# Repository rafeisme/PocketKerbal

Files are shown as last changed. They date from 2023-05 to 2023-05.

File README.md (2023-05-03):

# PocketKerbal
Kerbal Space Program Controller using PocketBeagle

(Soon to be) Home to KerbalController!

This is a personalized Kerbal Space Program console built using a PocketBeagle and kRPC. 

More information can be found on my Hackster Page: https://www.hackster.io/rfn1/pocketkerbal-ksp-console-using-pocketbeagle-krpc-d380ad 

The program you need to use/edit is called Project_1_v2
It is actually intiated using a run program. 
For these files, see https://github.com/rafeisme/ENGI301

Currently this repository houses the PCB files for PocketKerbal. These still need some work, but should be functional. The board is the same size as the actual console, and is designed to be fitted behind it. For the sake of simplicity, some of the unique buttons and switches have been temporarily swapped out for generic ones. 
In total there are:
15 toggle switches
4 buttons
20 resistors
2 joysticks
2 potentiometers
2 led bars
2 leds
1 sliding potentiometer
1 display

A more comprehensive parts list can be found on the Hackster Page. 

NOTE: The "PocketBeagle Device" had not been made when the PCB layout was done, so the example PocketBeagle is included here. The file for the custom PocketBeagle is included in the library.
NOTE: The project guidelines mentioned a 4"x5" maximum size, but in order to fit all of the components and be the size of the console, PocketKerbal is 12" x 6". It could be reduced if it was necessary. 
NOTE: The LCD screen was used as opposed to the SPI screen in my library. https://www.adafruit.com/product/181 

This is still a work in progress and will be updated soon.

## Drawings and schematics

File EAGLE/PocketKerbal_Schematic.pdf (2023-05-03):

3.3V P2_23 | SPI1.MOSI P2_25 | SPI1.MISO P2_27 | SPI1.CLK P2_29 | SPI1.CS P2_31 | GPIO45 P2_33 | AIN5(3.3V)GPIO86 P2_35 | GPIO59 | P2_02 GPIO58 | P2_04 GPIO57 | P2_06 GPIO60 | P2_08 GPIO52 | P2_10 PWR.BTN P2_12 | BAT.VIN P2_14 | BAT.TEMP P2_16 | GPIO47 | P2_18 GPIO64 | P2_20 GPIO46 | P2_22 GPIO44 | P2_24 RESET# P2_26 | PRU0.6 | P2_28 PRU0.3 | P2_30 PRU0.2 | P2_32 PRU0.5 | P2_34 AIN7(1.8V) P2_36

R3 D3

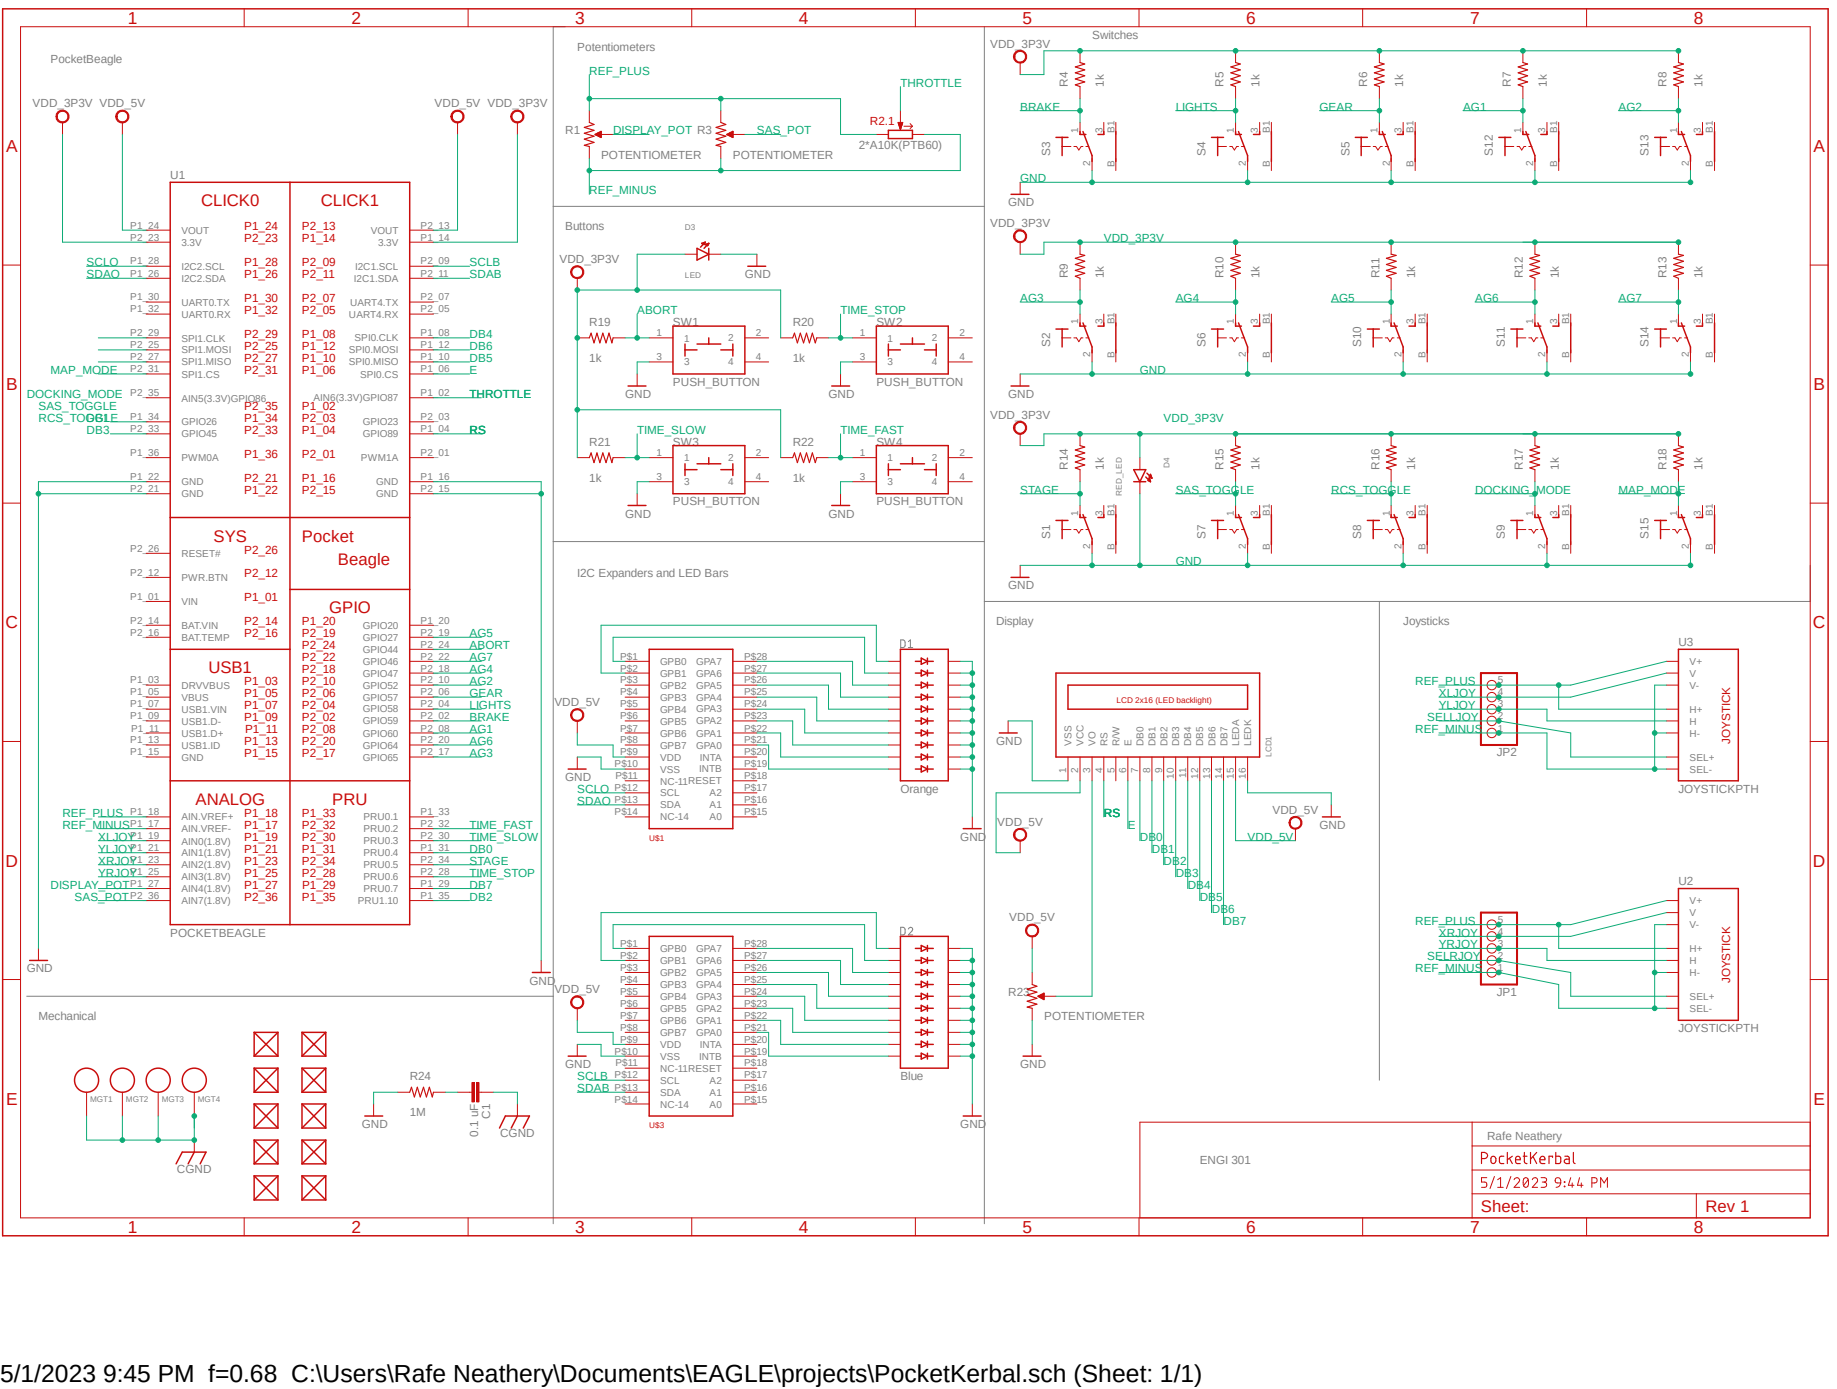
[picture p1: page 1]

VDD_5V VDD_3P3V | REF_PLUS | Switches

I2C Expanders and LED Bars

5/1/2023 9:45 PM f=0.68 C:\Users\Rafe Neathery\Documents\EAGLE\projects\PocketKerbal.sch (Sheet: 1/1)

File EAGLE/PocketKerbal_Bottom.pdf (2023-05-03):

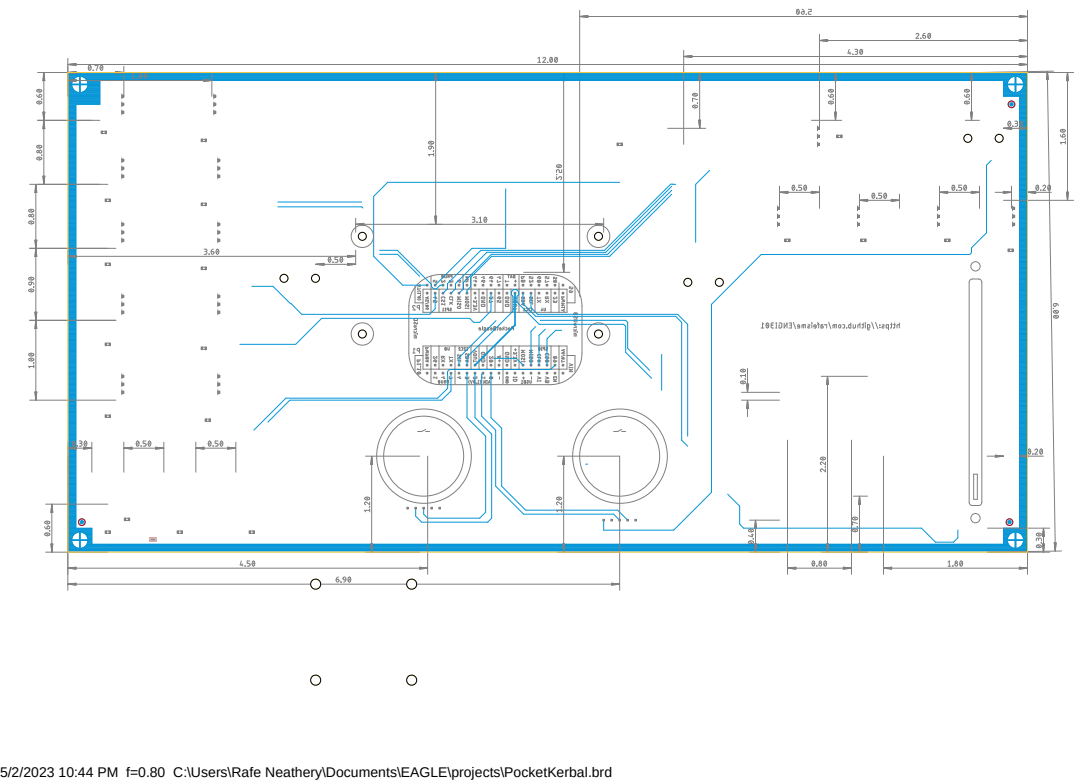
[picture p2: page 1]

5/2/2023 10:44 PM f=0.80 C:\Users\Rafe Neathery\Documents\EAGLE\projects\PocketKerbal.brd

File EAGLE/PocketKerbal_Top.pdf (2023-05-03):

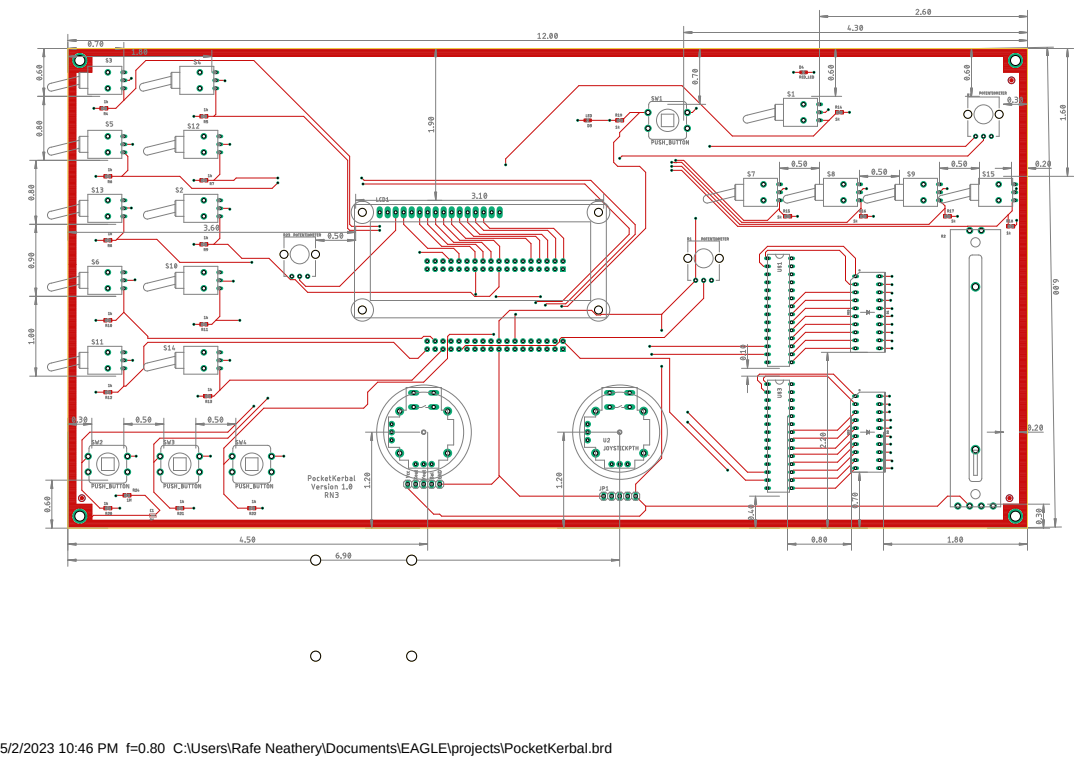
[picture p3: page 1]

5/2/2023 10:46 PM f=0.80 C:\Users\Rafe Neathery\Documents\EAGLE\projects\PocketKerbal.brd

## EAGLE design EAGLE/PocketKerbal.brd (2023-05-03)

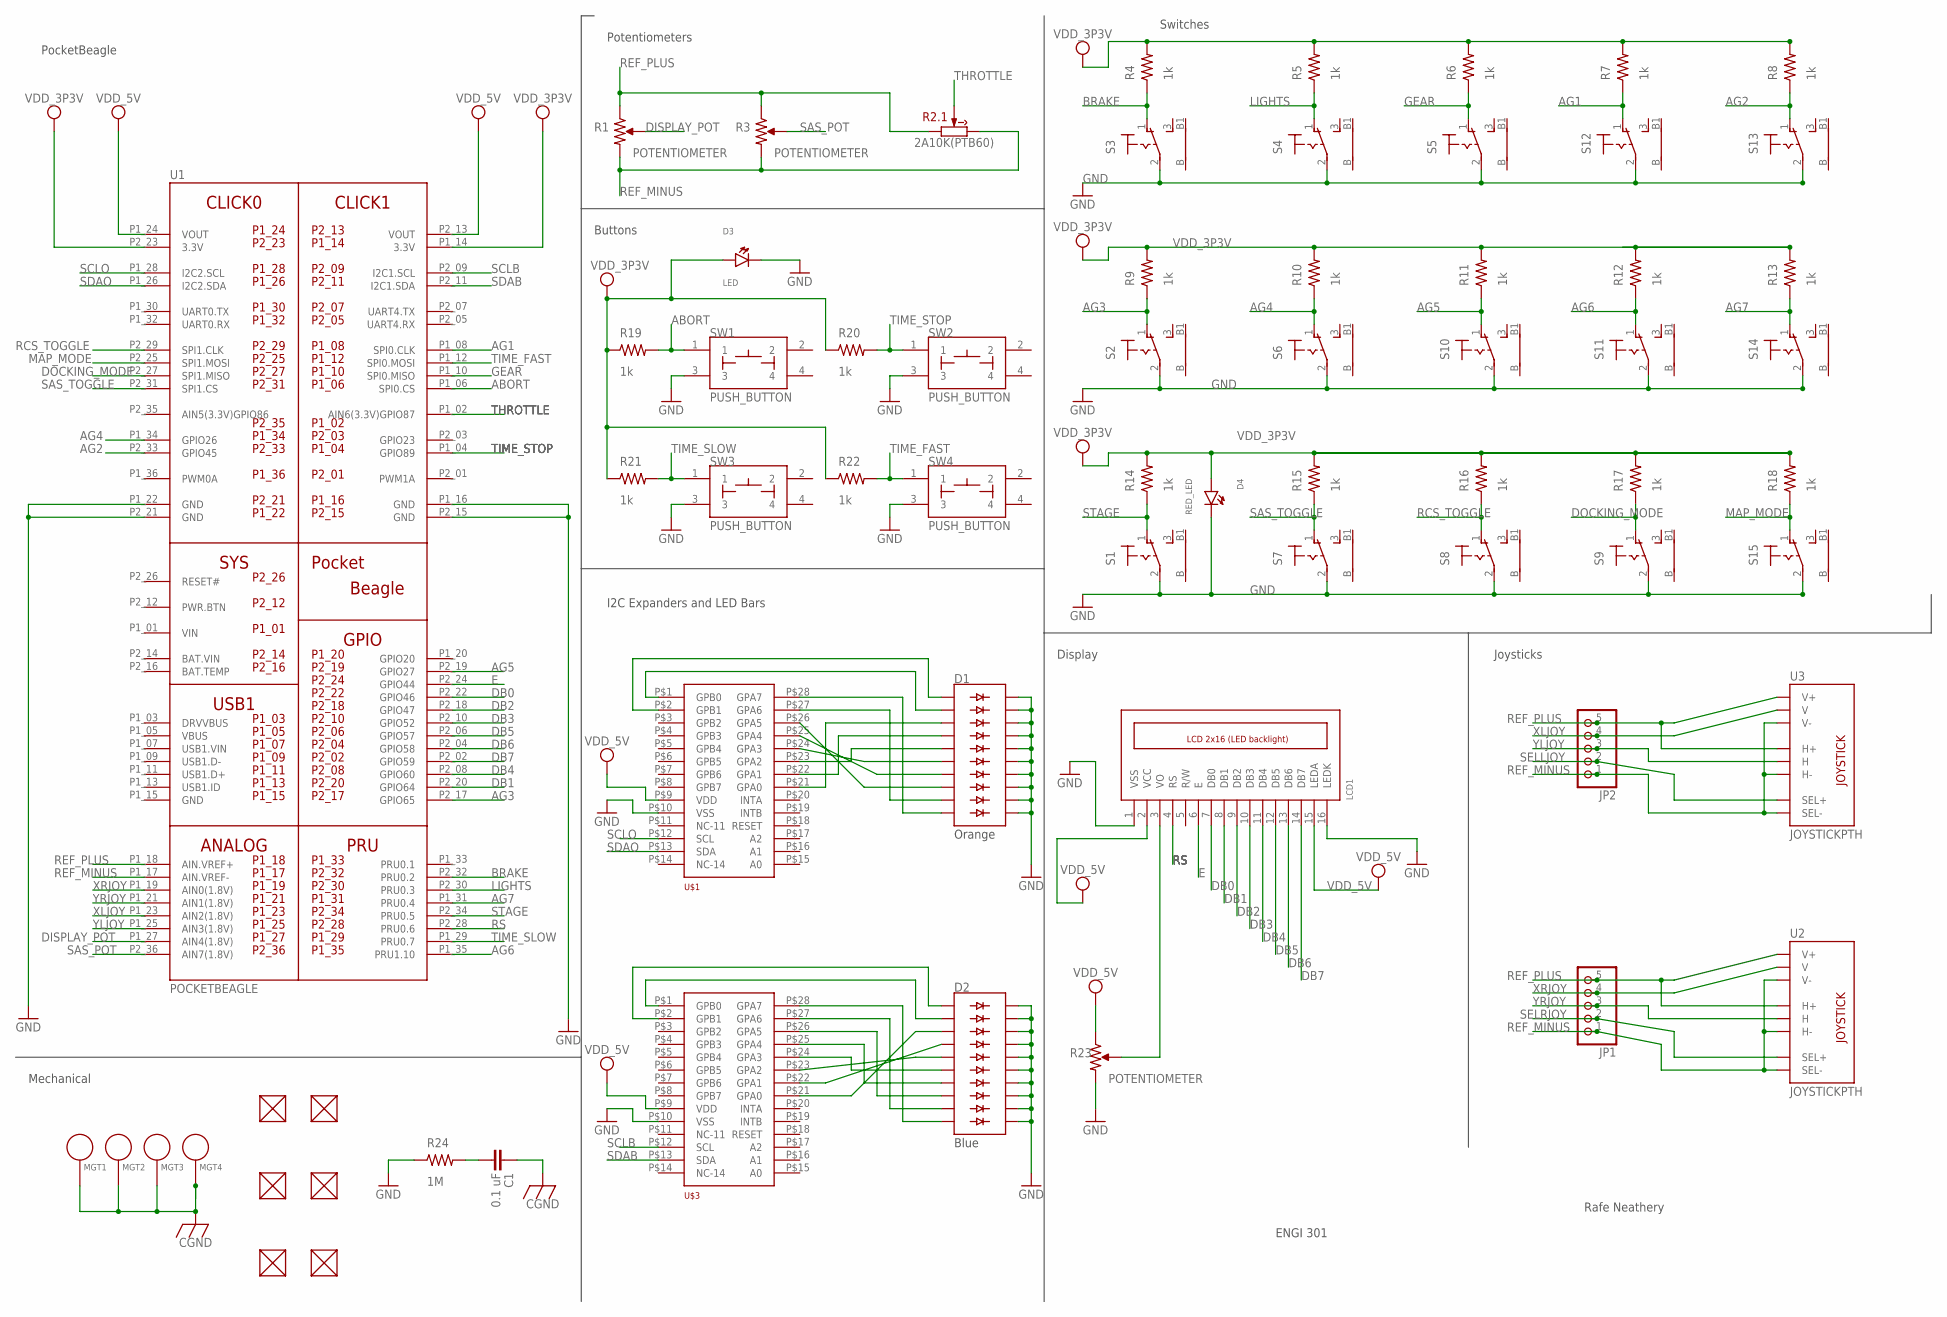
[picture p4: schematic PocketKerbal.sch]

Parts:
C1: 0.1 uF; C0402
D1, D2: RED; LED_BARGRAPH_10
D3: LED; EIA-STD
D4: RED_LED; EIA-STD
FUD1, FUD2, FUD5, FUD6, FUD9, FUD10: FIDUCIAL; FIDUCIAL_40MIL
JP1, JP2: PINHD-1X5; 1X05
LCD1: LCD_2X16_SIL; HY-1602F
MGT1, MGT2, MGT3, MGT4: MOUNTING_HOLE
R1, R3, R23: POTENTIOMETER; POT-PO90S
R2: 2A10K(PTB60); PTB6044
R4, R5, R6, R7, R8, R9, R10, R11, R12, R13, R14, R15, R16, R17, R18, R19, R20, R21, R22: 1k; R0603
R24: 1M; R0603
S1, S2, S3, S4, S5, S6, S7, S8, S9, S10, S11, S12, S13, S14, S15: 9070-1W
SW1, SW2, SW3, SW4: PUSH_BUTTON; BUTTON_12.5MM
U1: POCKETBEAGLE
U2, U3: JOYSTICKPTH; JOYSTICK
U$1, U$3: MCP23017-E/SP; DIP28

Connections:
ABORT: R19.2, SW1.1, U1.P1_06 (SPI0.CS)
AG1: R7.1, S12.1 (O), U1.P1_08 (SPI0.CLK)
AG2: R8.1, S13.1 (O), U1.P2_33 (GPIO45)
AG3: R9.1, S2.1 (O), U1.P2_17 (GPIO65)
AG4: R10.1, S6.1 (O), U1.P1_34 (GPIO26)
AG5: R11.1, S10.1 (O), U1.P2_19 (GPIO27)
AG6: R12.1, S11.1 (O), U1.P1_35 (PRU1.10)
AG7: R13.1, S14.1 (O), U1.P1_31 (PRU0.4)
BAT.VIN: U1.P2_14 (BAT.VIN)
BRAKE: R4.1, S3.1 (O), U1.P2_32 (PRU0.2)
CGND: C1.1, MGT1.P$1, MGT2.P$1, MGT3.P$1, MGT4.P$1
DB0: LCD1.7 (DB0), U1.P2_22 (GPIO46)
DB1: LCD1.8 (DB1), U1.P2_20 (GPIO64)
DB2: LCD1.9 (DB2), U1.P2_18 (GPIO47)
DB3: LCD1.10 (DB3), U1.P2_10 (GPIO52)
DB4: LCD1.11 (DB4), U1.P2_08 (GPIO60)
DB5: LCD1.12 (DB5), U1.P2_06 (GPIO57)
DB6: LCD1.13 (DB6), U1.P2_04 (GPIO58)
DB7: LCD1.14 (DB7), U1.P2_02 (GPIO59)
DISPLAY_POT: R1.S, U1.P1_27 (AIN4(1.8V))
DOCKING_MODE: R17.1, S9.1 (O), U1.P2_27 (SPI1.MISO)
E: LCD1.6 (E), U1.P2_24 (GPIO44)
GEAR: R6.1, S5.1 (O), U1.P1_10 (SPI0.MISO)
GND: D1.11 (C9), D1.12 (C8), D1.13 (C7), D1.14 (C6), D1.15 (C5), D1.16 (C4), D1.17 (C3), D1.18 (C2), D1.19 (C1), D1.20 (C), D2.11 (C9), D2.12 (C8), D2.13 (C7), D2.14 (C6), D2.15 (C5), D2.16 (C4), D2.17 (C3), D2.18 (C2), D2.19 (C1), D2.20 (C), D3.CATHODE, D4.CATHODE, LCD1.1 (VSS), LCD1.16 (LEDK), R23.CW, R24.1, S1.2, S2.2, S3.2, S4.2, S5.2, S6.2, S7.2, S8.2, S9.2, S10.2, S11.2, S12.2, S13.2, S14.2, S15.2, SW1.3, SW2.3, SW3.3, SW4.3, U1.P1_16 (GND), U1.P1_22 (GND), U1.P2_15 (GND), U1.P2_21 (GND), U$1.P$10 (VSS), U$3.P$10 (VSS)
LIGHTS: R5.1, S4.1 (O), U1.P2_30 (PRU0.3)
MAP_MODE: R18.1, S15.1 (O), U1.P2_25 (SPI1.MOSI)
unnamed: D2.3 (A2), U$3.P$21 (GPA0)
unnamed: D2.4 (A3), U$3.P$22 (GPA1)
unnamed: D2.10 (A9), U$3.P$28 (GPA7)
unnamed: D2.9 (A8), U$3.P$27 (GPA6)
unnamed: D2.8 (A7), U$3.P$26 (GPA5)
unnamed: D2.7 (A6), U$3.P$25 (GPA4)
unnamed: D2.6 (A5), U$3.P$24 (GPA3)
unnamed: D2.5 (A4), U$3.P$23 (GPA2)
unnamed: D2.2 (A1), U$3.P$1 (GPB0)
unnamed: D1.3 (A2), U$1.P$21 (GPA0)
unnamed: LCD1.3 (VO), R23.S
unnamed: D1.6 (A5), U$1.P$24 (GPA3)
unnamed: D1.7 (A6), U$1.P$25 (GPA4)
unnamed: D1.8 (A7), U$1.P$26 (GPA5)
unnamed: D1.9 (A8), U$1.P$27 (GPA6)
unnamed: D1.10 (A9), U$1.P$28 (GPA7)
unnamed: D1.2 (A1), U$1.P$1 (GPB0)
unnamed: D1.1 (A), U$1.P$2 (GPB1)
unnamed: D2.1 (A), U$3.P$2 (GPB1)
unnamed: C1.2, R24.2
unnamed: D1.5 (A4), U$1.P$23 (GPA2)
unnamed: D1.4 (A3), U$1.P$22 (GPA1)
RCS_TOGGLE: R16.1, S8.1 (O), U1.P2_29 (SPI1.CLK)
REF_MINUS: JP1.1, JP2.1, R1.CW, R2.A3 (CW), R3.CW, U1.P1_17 (AIN.VREF-), U2.B2A (SEL-), U2.H3 (H-), U2.V3 (V-), U3.B2A (SEL-), U3.H3 (H-), U3.V3 (V-)
REF_PLUS: JP1.5, JP2.5, R1.CCW, R2.A1 (CCW), R3.CCW, U1.P1_18 (AIN.VREF+), U2.H1 (H+), U2.V1 (V+), U3.H1 (H+), U3.V1 (V+)
RS: LCD1.4 (RS), U1.P2_28 (PRU0.6)
SAS_POT: R3.S, U1.P2_36 (AIN7(1.8V))
SAS_TOGGLE: R15.1, S7.1 (O), U1.P2_31 (SPI1.CS)
SCLB: U1.P2_09 (I2C1.SCL), U$3.P$12 (SCL)
SCLO: U1.P1_28 (I2C2.SCL), U$1.P$12 (SCL)
SDAB: U1.P2_11 (I2C1.SDA), U$3.P$13 (SDA)
SDAO: U1.P1_26 (I2C2.SDA), U$1.P$13 (SDA)
SELLJOY: JP2.2, U3.B1A (SEL+)
SELRJOY: JP1.2, U2.B1A (SEL+)
STAGE: R14.1, S1.1 (O), U1.P2_34 (PRU0.5)
THROTTLE: R2.A2 (W), U1.P1_02 (AIN6(3.3V)GPIO87)
TIME_FAST: R22.2, SW4.1, U1.P1_12 (SPI0.MOSI)
TIME_SLOW: R21.2, SW3.1, U1.P1_29 (PRU0.7)
TIME_STOP: R20.2, SW2.1, U1.P1_04 (GPIO89)
VDD_3P3V: D3.ANODE, D4.ANODE, R4.2, R5.2, R6.2, R7.2, R8.2, R9.2, R10.2, R11.2, R12.2, R13.2, R14.2, R15.2, R16.2, R17.2, R18.2, R19.1, R20.1, R21.1, R22.1, U1.P1_14 (3.3V), U1.P2_23 (3.3V)
VDD_5V: LCD1.2 (VCC), LCD1.15 (LEDA), R23.CCW, U1.P1_24 (VOUT), U1.P2_13 (VOUT), U$1.P$9 (VDD), U$3.P$9 (VDD)
VIN: U1.P1_01 (VIN)
XLJOY: JP2.4, U1.P1_23 (AIN2(1.8V)), U3.V2 (V)
XRJOY: JP1.4, U1.P1_19 (AIN0(1.8V)), U2.V2 (V)
YLJOY: JP2.3, U1.P1_25 (AIN3(1.8V)), U3.H2 (H)
YRJOY: JP1.3, U1.P1_21 (AIN1(1.8V)), U2.H2 (H)

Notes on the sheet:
PocketBeagle
Potentiometers
Buttons
I2C Expanders and LED Bars
Switches
Joysticks
Display
Blue
Orange
Mechanical
ENGI 301
Rafe Neathery

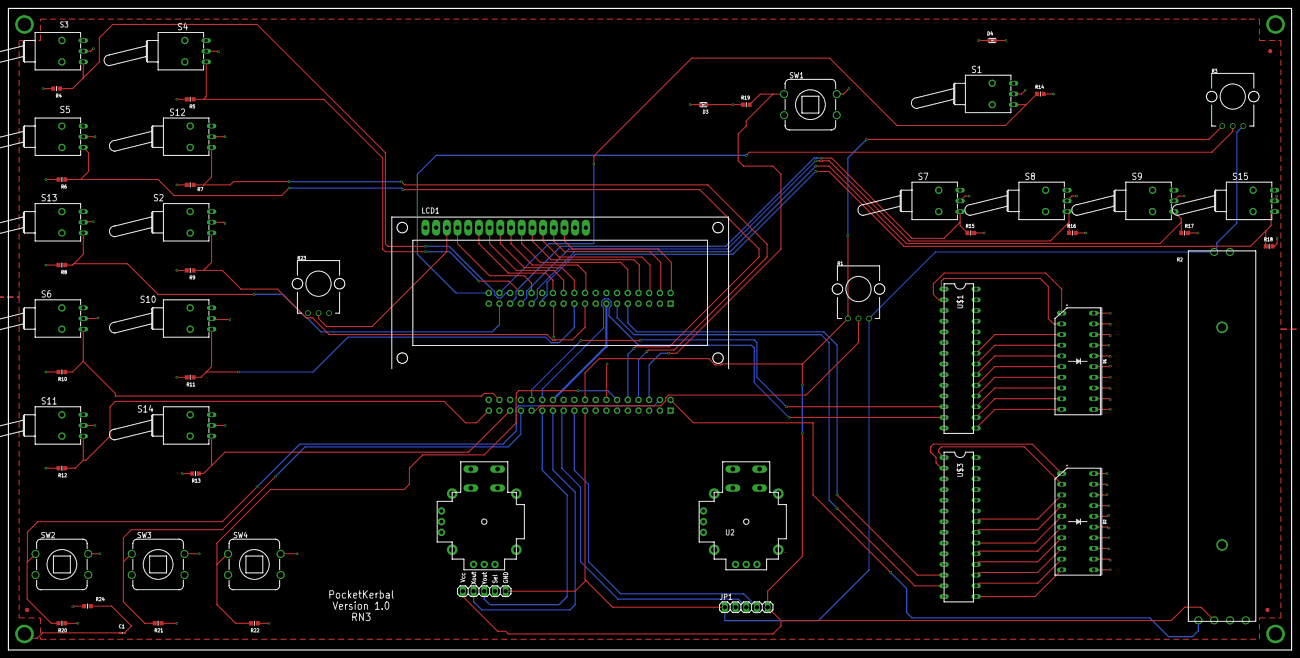
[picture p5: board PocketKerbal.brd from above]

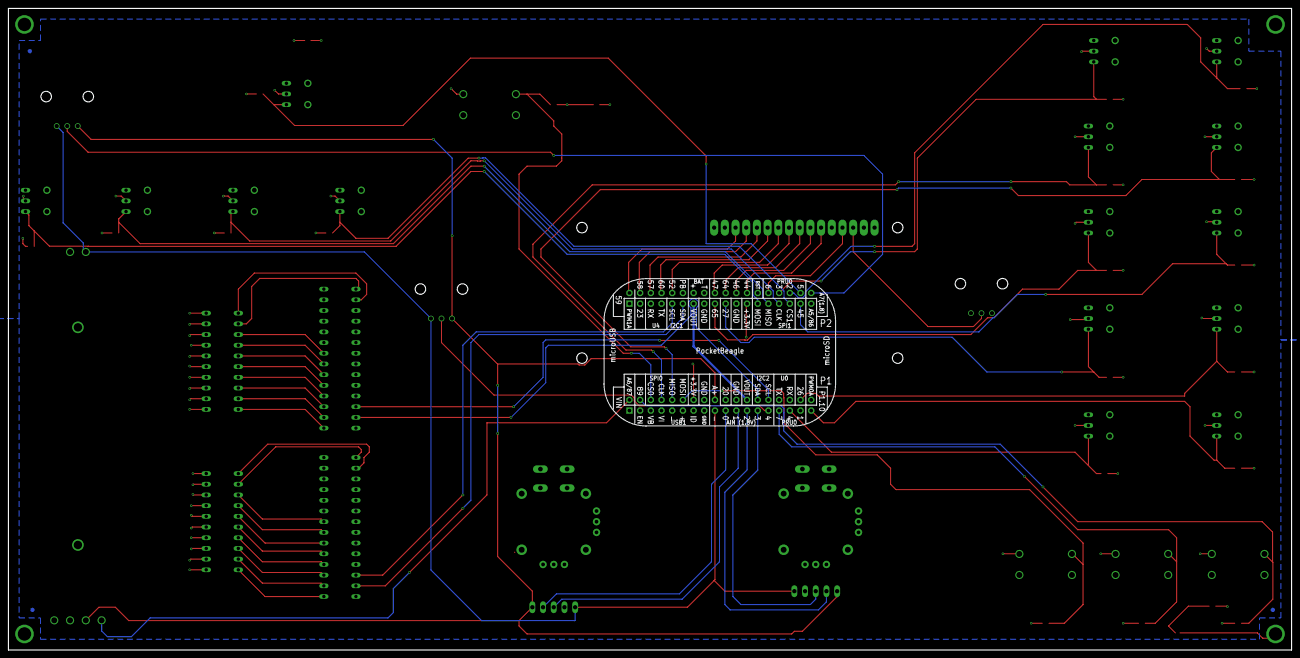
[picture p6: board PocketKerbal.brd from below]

Board: 4 copper layers, 304.8 x 152.4 mm, 66 parts (4 on the bottom side), 70 nets.

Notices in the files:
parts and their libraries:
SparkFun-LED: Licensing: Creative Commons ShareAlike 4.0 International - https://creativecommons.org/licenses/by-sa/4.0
